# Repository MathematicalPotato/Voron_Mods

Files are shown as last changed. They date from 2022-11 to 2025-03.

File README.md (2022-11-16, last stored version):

# V0 Universal Belted Z
This is a new belted Z mod for the Voron Zero. It drops the Z drive below the bottom frame extrusion. This allows full range of motion for both stock (V0.0/V0.1/V0.2) and Kirigami setups. It has been tested with 5:1 gearing up to 300mm/s at 1000mm/s/s z accels and 200mm/s at 3000mm/s/s with an OMC-17HS08-1004S motor set to run_current: 0.5.

If you are installing fresh you will need to install the motor plate after installing the rear panel (the rest of the Z drive can be installed before).  You will also need to install the bedmount prior to mounting the back panel for the stock bed setups as they bolt from the back.  For the Kirigami the whole thing can be installed without removing the panel.

For the Z Drive itself, you will need three F695 bearings, a 200mm GT2 belt loop, and a 5mm OD by 75mm long shaft with flats for pulleys.  Longer shafts will also work (I am using a 100mm currently because I was too lazy to cut it shorted) as long as you set the end flush with the pulley in the 80 tooth, but you'll need to restrain cables to ensure they don't get near the shaft.

For the upper idler there are two models, one that can use F695 bearings and one for F623 bearings. I highly recommend using F623 bearings as the belt alignment will be a little bit better and if you're building a V0 you probably have two extras.

For bolt/nut/heatset counts they should all be in place in the CAD, each configuration has slight differences.

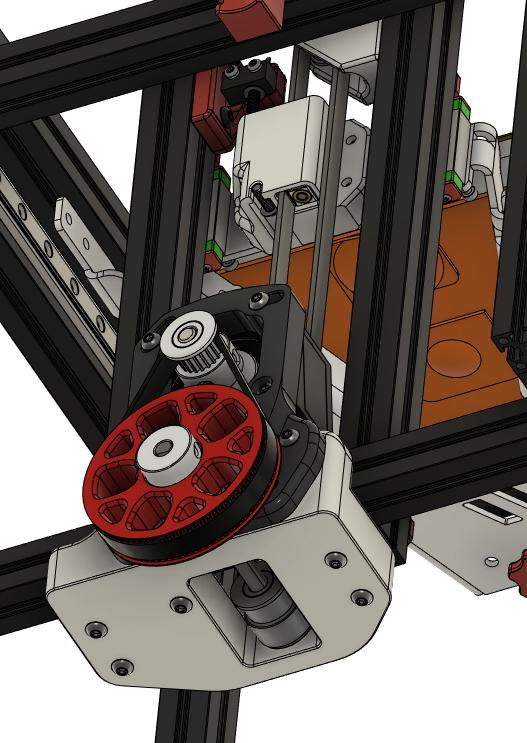
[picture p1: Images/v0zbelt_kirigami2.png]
ZBelt-Pic001

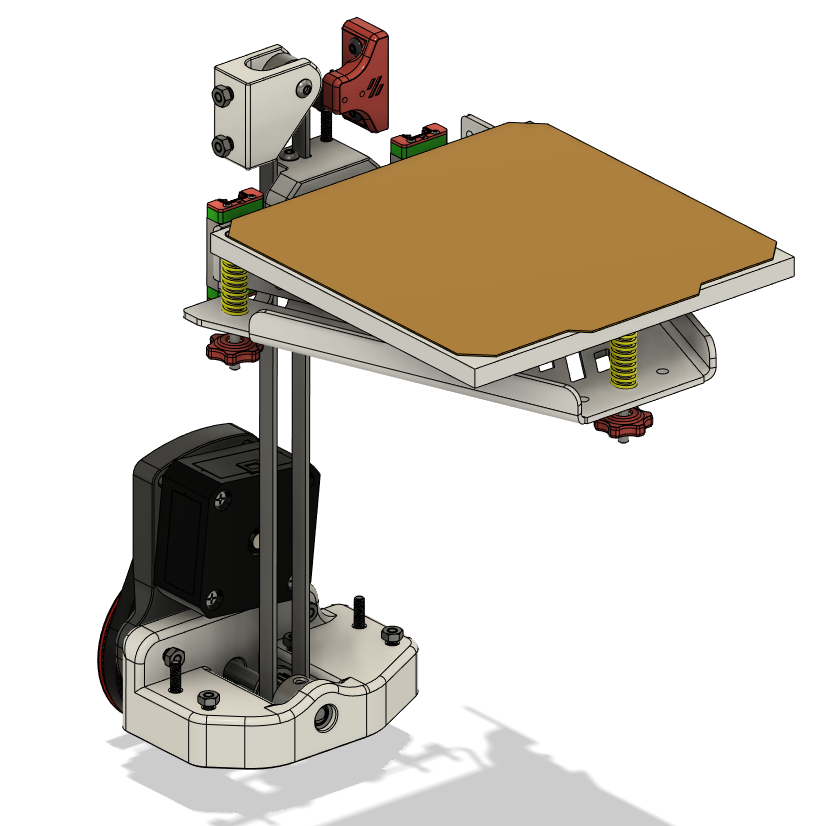
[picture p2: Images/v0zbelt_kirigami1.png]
ZBelt-Pic002

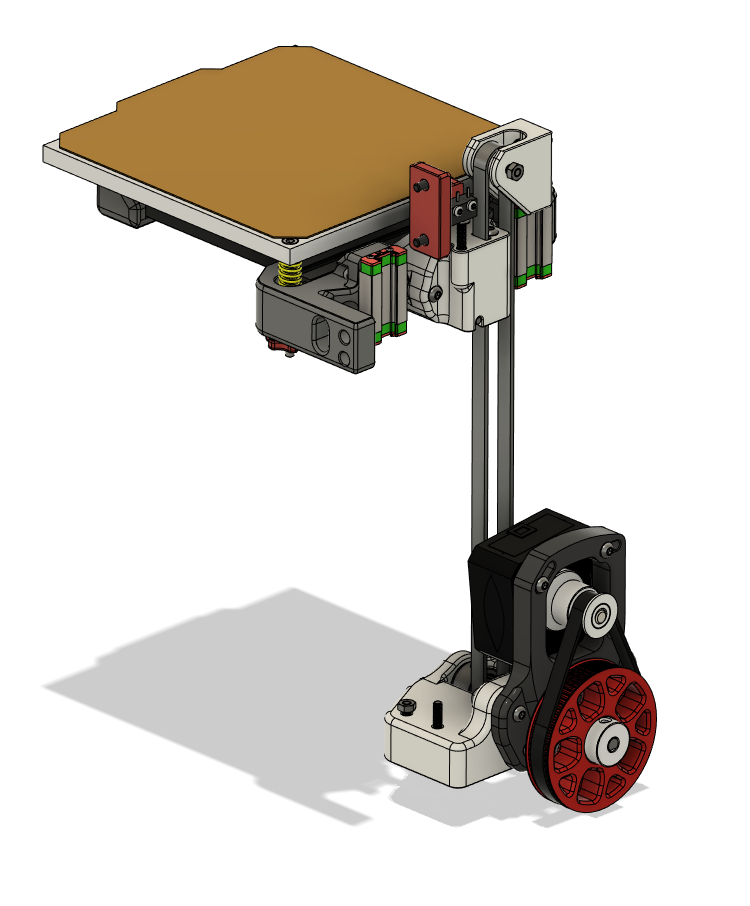
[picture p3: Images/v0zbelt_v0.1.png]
ZBelt-Pic003


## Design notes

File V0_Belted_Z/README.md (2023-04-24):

# V0 Universal Belted Z
This is a new belted Z mod for the Voron Zero. It drops the Z drive below the bottom frame extrusion. This allows full range of motion for both stock (V0.0/V0.1/V0.2) and Kirigami setups. It has been tested with 5:1 gearing up to 300mm/s at 1000mm/s/s z accels and 200mm/s at 3000mm/s/s with an OMC-17HS08-1004S motor set to run_current: 0.5.

If you are installing fresh you will need to install the motor plate after installing the rear panel (the rest of the Z drive can be installed before).  You will also need to install the bedmount prior to mounting the back panel for the stock bed setups as they bolt from the back.  For the Kirigami the whole thing can be installed without removing the panel.

For the Z Drive itself, you will need three F695 bearings, a 200mm GT2 belt loop, and a 5mm OD by 75mm long shaft with flats for pulleys.  Longer shafts will also work (I am using a 100mm currently because I was too lazy to cut it shorted) as long as you set the end flush with the pulley in the 80 tooth, but you'll need to restrain cables to ensure they don't get near the shaft.

For the upper idler there are two models, one that can use F695 bearings and one for F623 bearings. I highly recommend using F623 bearings as the belt alignment will be a little bit better and if you're building a V0 you probably have two extras.

For bolt/nut/heatset counts they should all be in place in the CAD, each configuration has slight differences.

## Updates

### 2023-04-24

It was brought to my attention by mapaba#0044 on the Discord that there were some clearance issues with the rear skirt and power inlet on the V0.2 which could be fixed by mirroring the assembly to shift the z drive further from the power inlet.  All components have been switched to a mirrored assembly for better compatibility with V0.2 parts while maintaining compatibility with the other configurations as well.  

The old parts are still fine for V0.0 or V0.1 builds, but for new build V0.2 or upgrading to V0.2 from a prior revision it is recommended to use the new mirrored assembly.  Drilling a hole in the rear panel may be required to use the mirrored z-min endstop. It is recommended to use the newer z-max endstop configuration.

This mod is compatible with V0.0, V0.1, and V0.2 in either Kirigami or Stock Bed configurations as of 2023-04-24.

## Pictures

### Kirigami Bed

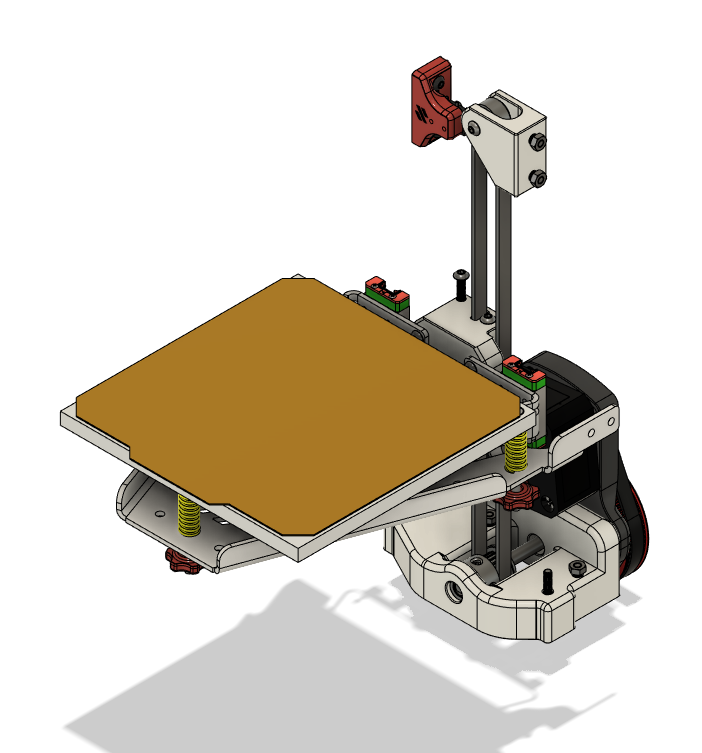
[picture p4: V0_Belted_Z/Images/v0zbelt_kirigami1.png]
ZBelt-Pic001

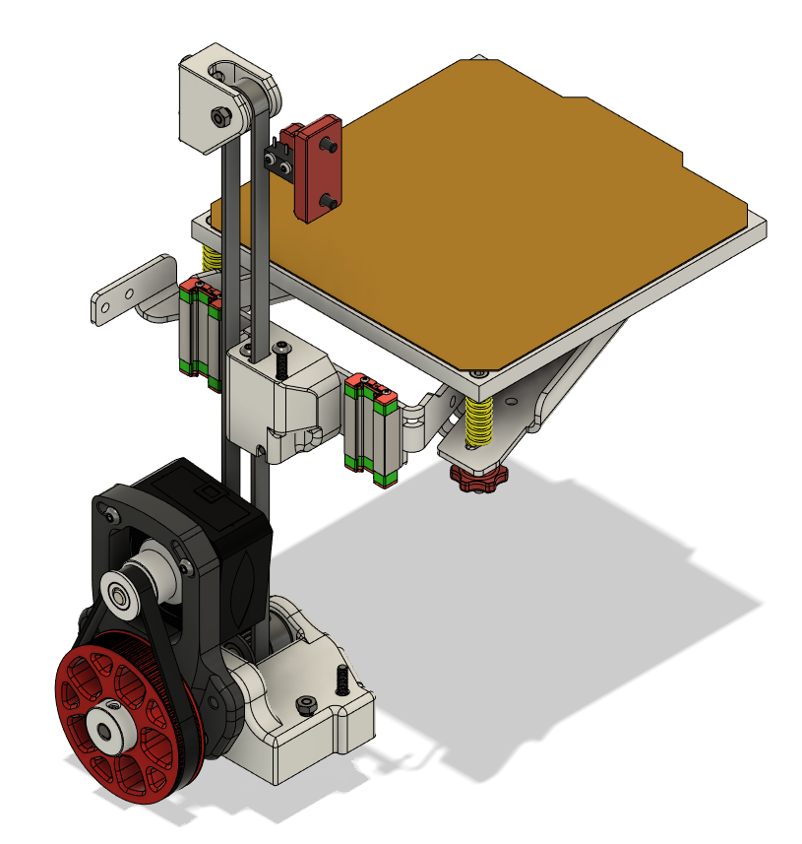
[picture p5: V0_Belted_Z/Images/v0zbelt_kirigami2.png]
ZBelt-Pic002


### Stock Bed

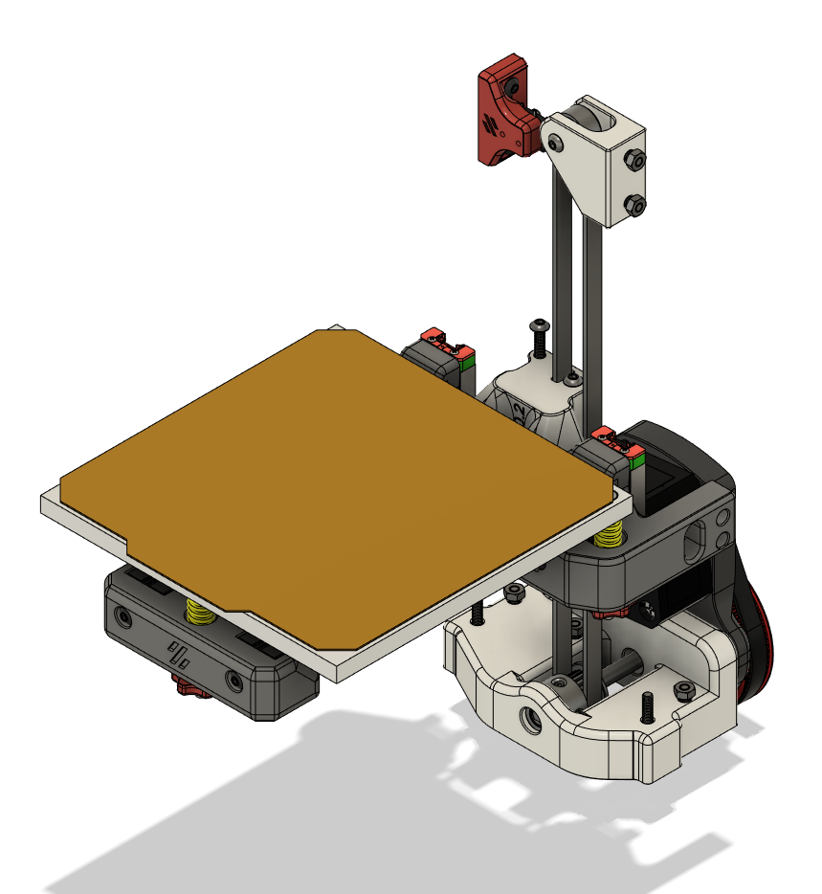
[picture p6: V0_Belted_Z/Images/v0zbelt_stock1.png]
ZBelt-Pic003


### V0.2 Compatibility

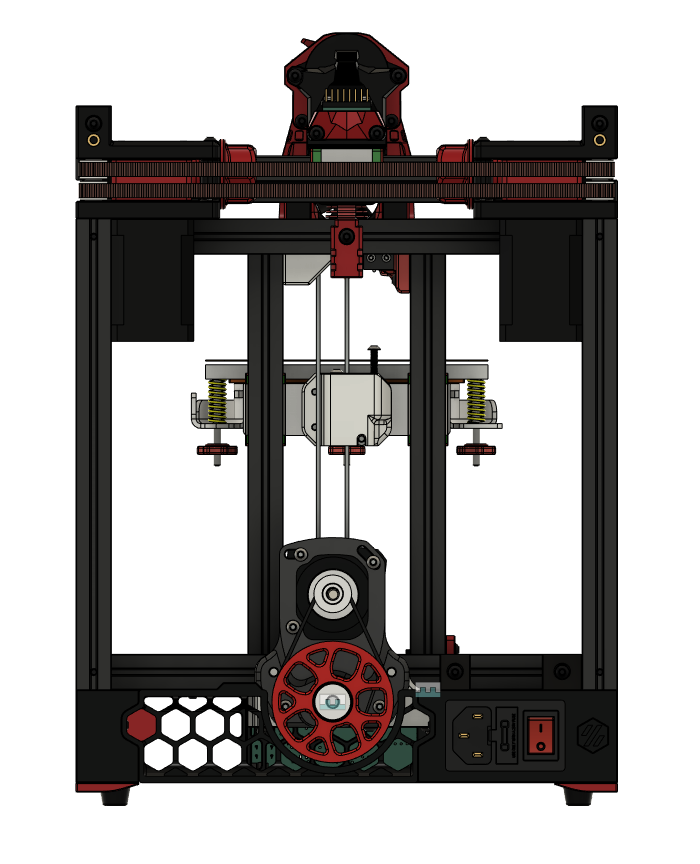
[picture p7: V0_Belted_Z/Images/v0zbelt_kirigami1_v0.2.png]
ZBelt-Pic004

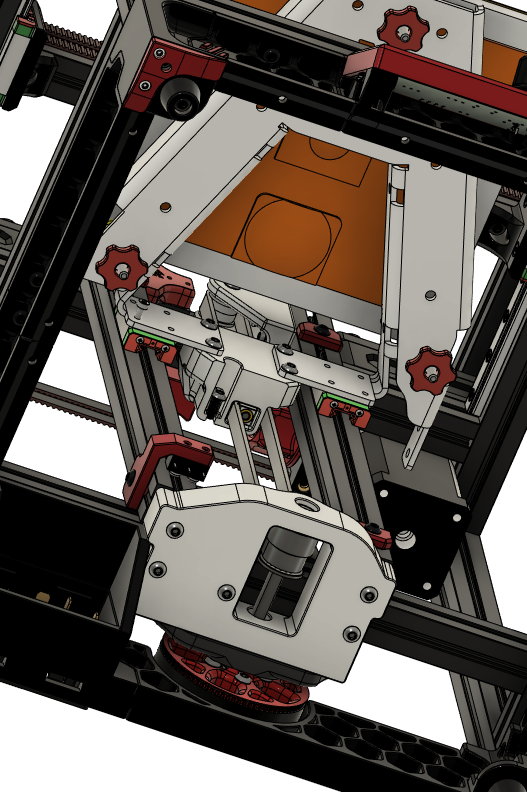
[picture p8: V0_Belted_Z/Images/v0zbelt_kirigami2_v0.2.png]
ZBelt-Pic005


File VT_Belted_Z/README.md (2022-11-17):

# VT Belted Z
This is a belted Z mod candidate for the Voron Trident.  It use three modified V2.4 Z drives in place of the integrated leadscrew steppers for Z motion.  

Parts are currently designed for 9mm belts, but 6mm belts could be used by swapping to a 6mm pulley and adding extra spacers around the idler bearings.

Check motor datasheets and try to get Z motors that have at least 0.2 mNm of detent torque, most stepper motors that are at least 48mm long will have enough.  250mm builds with beds over 8mm thick, 300mm builds with beds over 6mm thick, and all 350mm builds are not recommended as the Z motors will likely not have a high enough detent torque to hold the bed on power off.  This can cause the bed to drop which can have the same effect as spinning steppers by hand, a charge will be sent back to stepper drivers and controller board which can fry components.

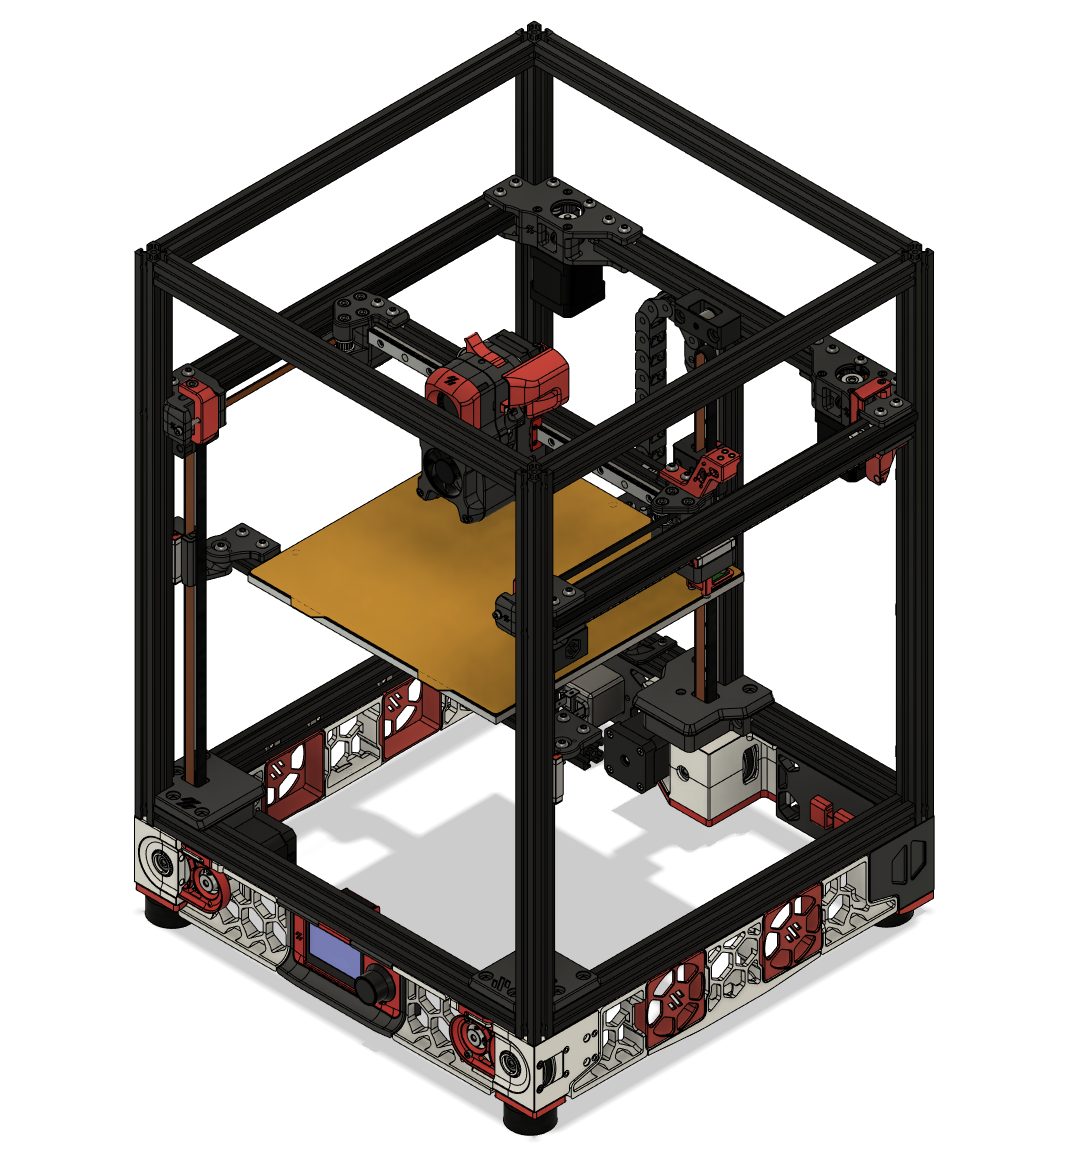
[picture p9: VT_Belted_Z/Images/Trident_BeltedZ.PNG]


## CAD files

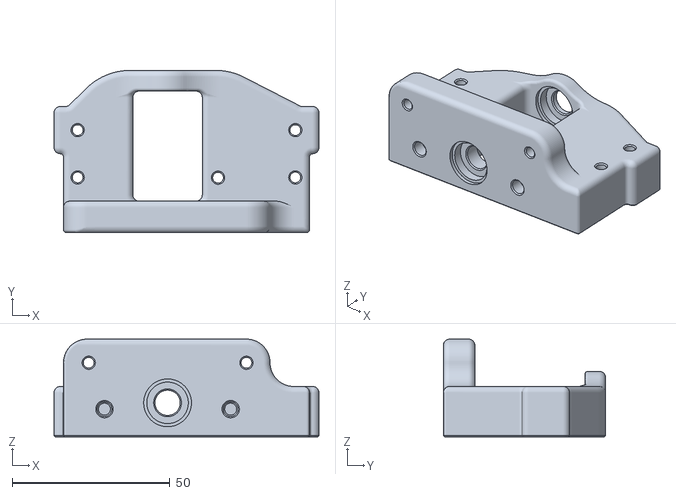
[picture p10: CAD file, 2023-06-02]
V0_Belted_Z/STLs/Mirrored Configuration - V0.2, V0.1, V0.0/z_drive_bottom_idler_pulleys_x1.stl
84.0 x 51.4 x 31.0

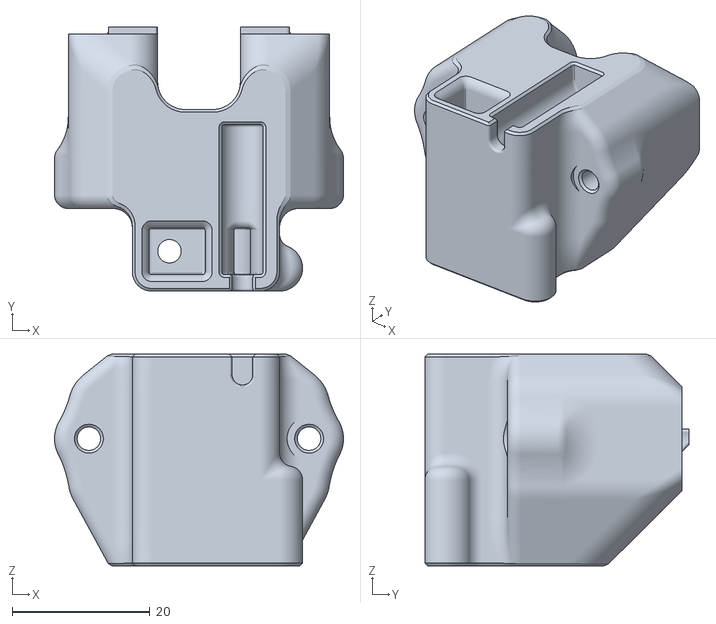
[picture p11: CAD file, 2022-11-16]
V0_Belted_Z/STLs/Original Configuration - V0.1 and V0.0/Bed_Mount_Extrusions_V0.1.stl
42.0 x 38.4 x 30.8

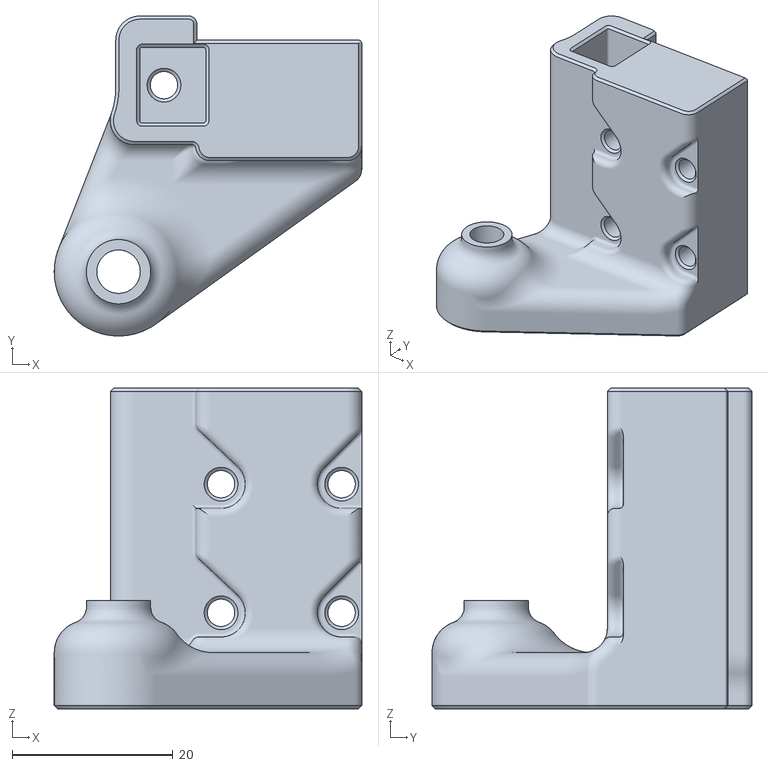
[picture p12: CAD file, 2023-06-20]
VT_Belted_Z/STLs/Trident_BeltedZ_Drives/front_left_drive/left_carriage_mount.stl
38.2 x 39.8 x 39.9

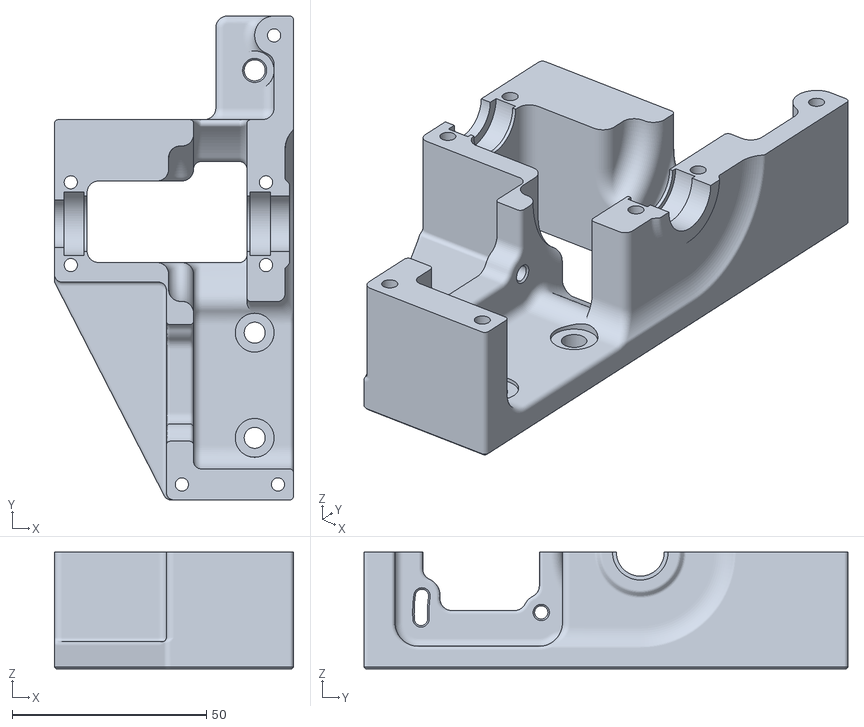
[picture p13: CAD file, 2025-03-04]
VT_Belted_Z/STLs/Trident_BeltedZ_Drives/rear_drive/rear_z_top.stl
61.5 x 124.6 x 30.0

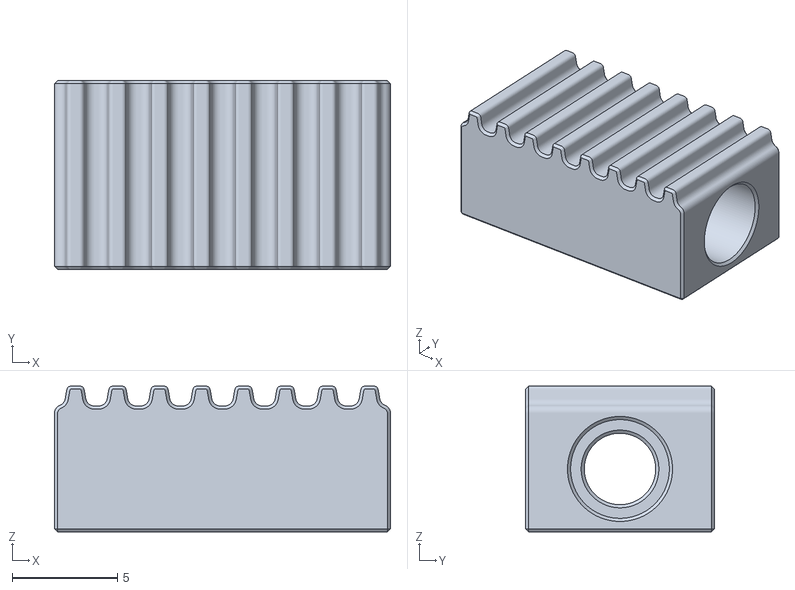
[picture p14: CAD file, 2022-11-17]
VT_Belted_Z/STLs/Trident_BeltedZ_Drives/tensioner_slider_x3.stl
16.0 x 9.00 x 6.95

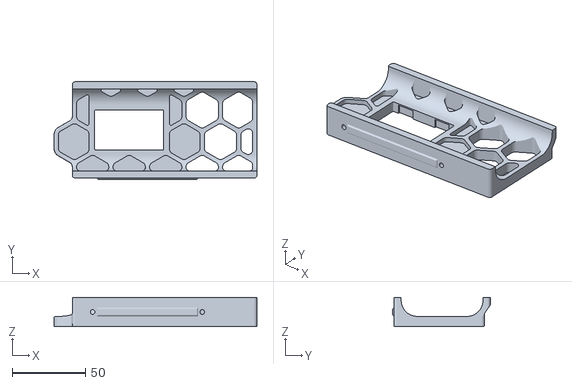
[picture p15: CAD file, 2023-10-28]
VT_Belted_Z/STLs/Trident_BeltedZ_Skirts/power_inlet_adamstech_300.stl
139.0 x 66.8 x 20.0

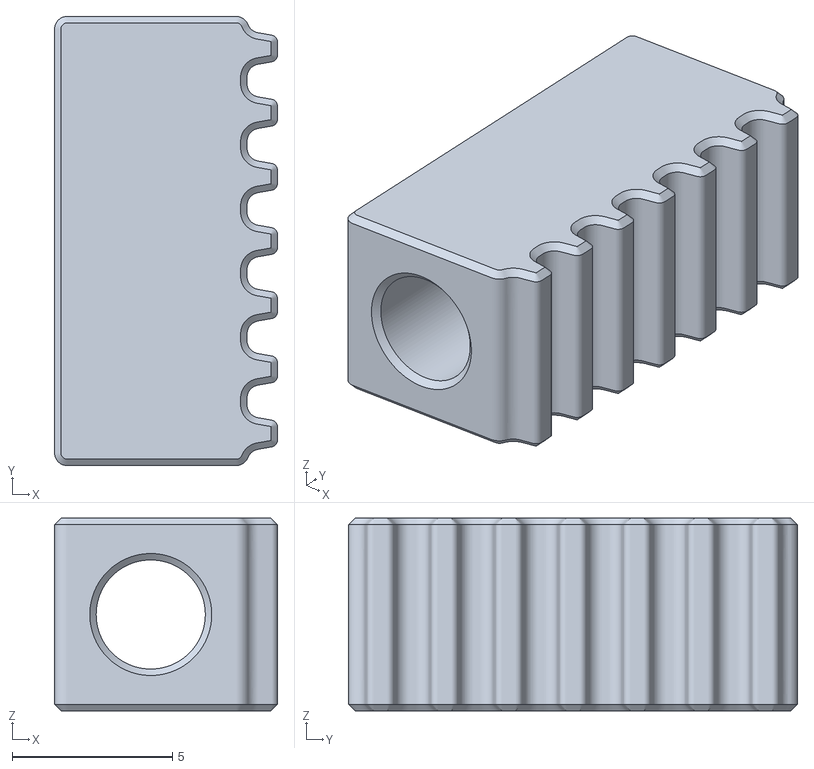
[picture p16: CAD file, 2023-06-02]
V0_Belted_Z/STLs/Mirrored Configuration - V0.2, V0.1, V0.0/Bed_Mount_Tensioning_Block.stl
6.95 x 14.0 x 6.00

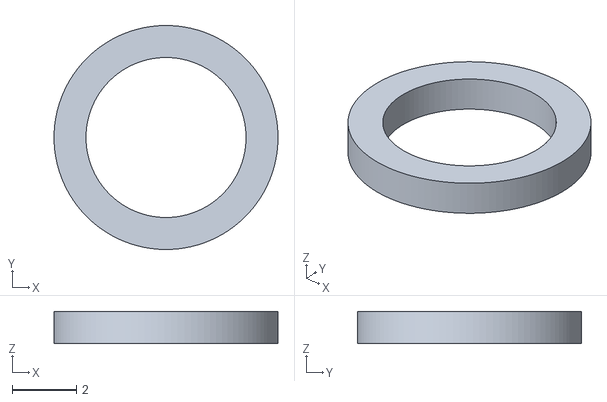
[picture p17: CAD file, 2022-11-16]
V0_Belted_Z/STLs/Original Configuration - V0.1 and V0.0/Printed-PulleySpacer-OPTIONAL.stl
7.00 x 7.00 x 1.00

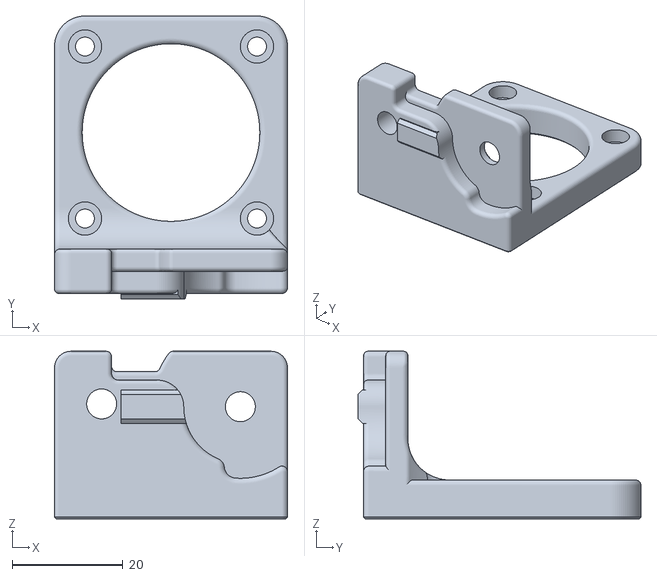
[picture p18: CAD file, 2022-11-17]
VT_Belted_Z/STLs/Trident_BeltedZ_Drives/front_left_drive/left_z_drive_motor_mount.stl
42.0 x 51.0 x 30.2

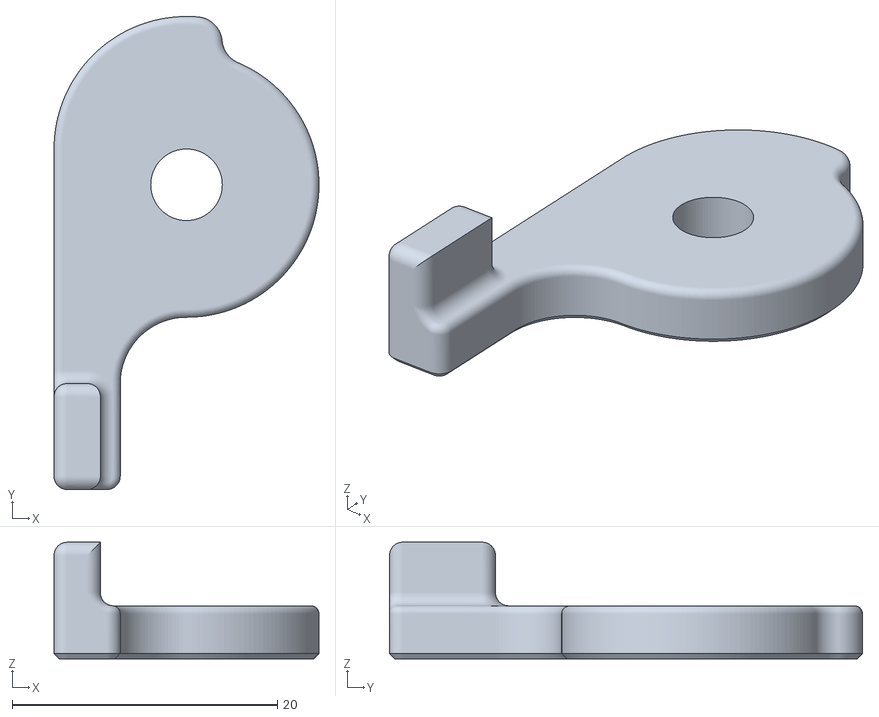
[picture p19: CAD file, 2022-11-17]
VT_Belted_Z/STLs/Trident_BeltedZ_Drives/front_right_drive/[a]_right_z_drive_tensioner.stl
20.0 x 35.7 x 8.80

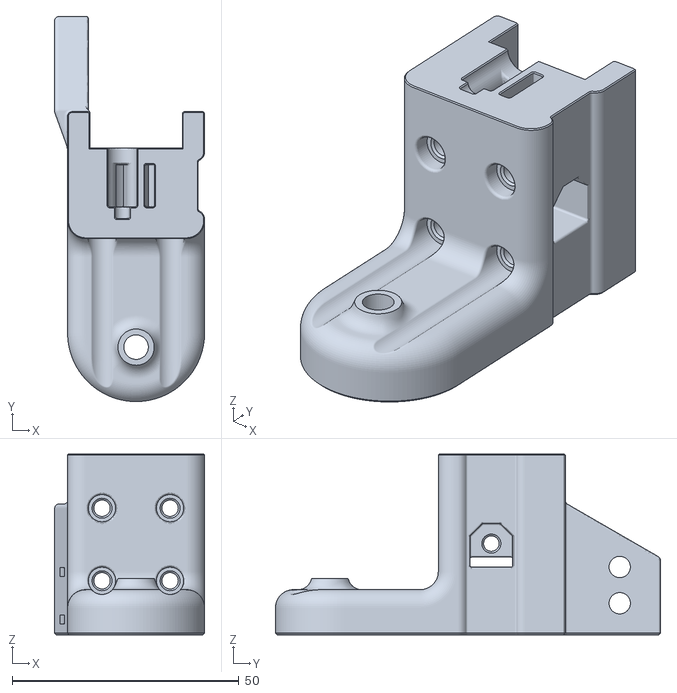
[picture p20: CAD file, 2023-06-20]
VT_Belted_Z/STLs/Trident_BeltedZ_Drives/rear_drive/rear_z_carriage_2hole.stl
33.1 x 84.9 x 39.9

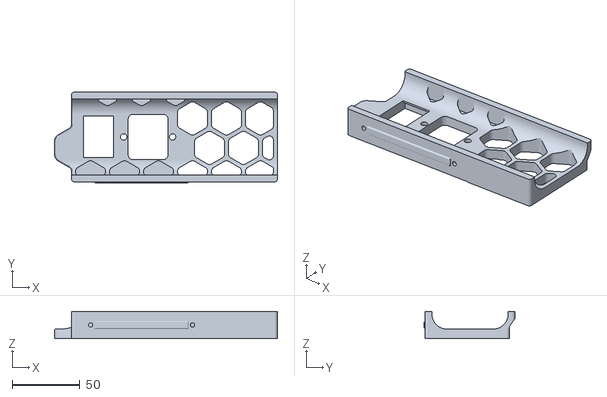
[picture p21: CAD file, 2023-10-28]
VT_Belted_Z/STLs/Trident_BeltedZ_Skirts/power_inlet_filtered_350.stl
164.0 x 66.8 x 20.0

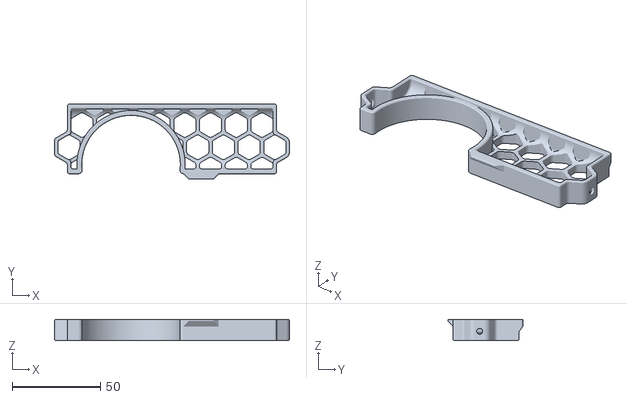
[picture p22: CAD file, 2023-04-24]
V0_Belted_Z/STLs/Mirrored Configuration - V0.2, V0.1, V0.0/z_rear_skirt_belted_z.stl
132.8 x 42.5 x 12.0

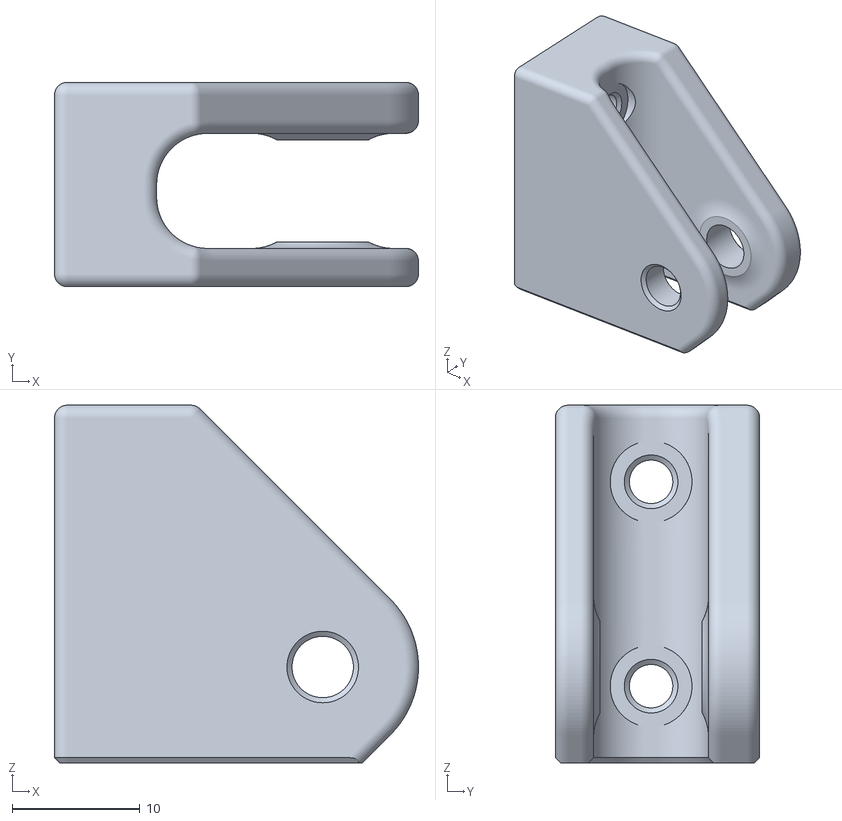
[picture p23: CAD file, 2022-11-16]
V0_Belted_Z/STLs/Original Configuration - V0.1 and V0.0/z_top_idler_F695.stl
28.5 x 16.0 x 28.0

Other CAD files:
VT_Belted_Z/STLs/Trident_BeltedZ_Drives/front_right_drive/right_carriage_mount.stl
VT_Belted_Z/STLs/Trident_BeltedZ_Drives/front_left_drive/[a]_left_z_drive_base_plate.stl
VT_Belted_Z/STLs/Trident_BeltedZ_Drives/front_right_drive/right_z_drive_body_outer.stl
VT_Belted_Z/STLs/Trident_BeltedZ_Drives/rear_drive/rear_z_bottom.stl
V0_Belted_Z/STLs/Mirrored Configuration - V0.2, V0.1, V0.0/Bed_Mount_Extrusions_V0.0+0.2.stl
V0_Belted_Z/STLs/Mirrored Configuration - V0.2, V0.1, V0.0/Bed_Mount_Extrusions_V0.1.stl
V0_Belted_Z/STLs/Mirrored Configuration - V0.2, V0.1, V0.0/Bed_Mount_Kirigami.stl
V0_Belted_Z/STLs/Mirrored Configuration - V0.2, V0.1, V0.0/M4-80T-Gear.stl
V0_Belted_Z/STLs/Mirrored Configuration - V0.2, V0.1, V0.0/z_drive_motor_mount_pulleys_x1.stl
V0_Belted_Z/STLs/Mirrored Configuration - V0.2, V0.1, V0.0/z_endstop_mirror.stl
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

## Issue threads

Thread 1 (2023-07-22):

How many N.m do we need for 350mm?

pasha4ur, 2023-07-22:
Hello

Thank you for this mod.

How many N.m do we need for 350 mm with standard thickness?

You wrote:
> try to get Z motors that have at least 0.2 mNm of detent torque

For example 40 mm motor (I have this):

Cloudray Nema 17 Stepper Motor  40mm 0.42 N.m 1.7A 2 Phase
https://ae01.alicdn.com/kf/Heec5ff7f53b0446ba1fe4dcbd27f9fbbB.jpg
https://www.aliexpress.com/item/1005001303445983.html

or 60 mm:

Nema17 Stepper Motor 60mm 2 Phase 71 N.m 1.8A Stepper Motor
https://www.aliexpress.com/item/4000934544704.html

I'm building Trident with build volume 450 mm. But for this moment I have standard 350 mm build plate.

MathematicalPotato, 2023-09-14:
You're looking for the detent torque rating of the steppers not the holding torque.  Holding torque is how much torque it takes to turn the motor shaft when powered on and running at the rated current.  Detent torque is the amount of torque it takes to turn the shaft when no power is applied.  For beds, we are more interested in the detent torque rating as if this value is not spec'd high enough compared to the Z axis moving mass, the bed will drop on power off.  This can break components depending on the weight of the bed or fry electronics if the steppers back feed into the controller board.

For reference, a torque rating of 1Nm with a 16T/20T pulley on the motor shaft and 1:1 gearing should hold about 40lbs per motor.  This reference value is higher than the powered (holding) torque rating of pretty much every NEMA17 stepper targeted at 3DP.  For steppers that do not have data sheets or that do not have detent torque listed on the data sheets I would either compare to a comparable LDO model or assume detent torque is somewhere around 2-4% of the holding torque.  It can also be measured using an arm of a known length bolted to the motor and pushing that shaft against a kitchen scale and recording the maximum mass.  It takes some math to get back to detent torque, but it's a good method if there isn't any other data.

The 60mm long NEMA17s seem to have the highest detent torque available, but they still top out around 0.030Nm of detent torque.  This value should be able to hold about 3.7lbs per motor without power on 5:1 gearing.  My belted Z design uses 3 drives which would only be able to hold an absolute maximum of ~11.1lbs with these motors.  Based on some quick math, I estimate a 9mm thick 350mm bed assembly (with bed mounts, extrusions, etc) for a Trident would weight approximately 13lbs.  This also doesn't account for print mass.  With these values, I would not recommend running 5:1 belted Z for machines larger than 300mm.

I would recommend looking into worm gear Z drives similar to the style used on the Z axis of the Annex Engineering K1/K2 and Redoubt as they can provide significantly higher gear reductions.  A minimum of 10:1 gearing would be ideal for your machine size.

Closed 2023-09-14.

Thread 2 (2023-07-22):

Can you make it compatible with Idex's idlers?

pasha4ur, 2023-07-22:
Hello.

With belted Z and Idex trident can shine with more power. )

https://github.com/FrankenVoron/Tridex/blob/main/Documentation/Assembly_Manual_Tridex_Front_Idler.pdf

MathematicalPotato, 2023-09-14:
This should be possible with the existing parts, but would likely require shorter Z rails, taller bed standoffs, and a reduced Z travel compared to a stock machine in the same frame size.  It is outside the scope of this mod, but a lot of the design elements could be reused.

Closed 2023-09-14.

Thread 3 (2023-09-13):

SolidWorks Corporation - STEP Processor Error Log

pasha4ur, 2023-09-13:
Hello

I know that you don't care about users and don't answer but your new step file has problems:

SolidWorks Corporation - STEP Processor Error Log
STEP Post Processor

Error: Encountered invalid record index.
STEP-in did not complete successfully.

MathematicalPotato, 2023-09-14:
I rarely check Github as don't make regular updates to these mods and I typically get <5 requests per year for updates.  Previously they also all have been though Discord, either in DMs or on the Voron server.  I am far more responsive on Discord (mathematicalpotato) if you need more immediate assistance with an issue or have a quick question.

I am unsure which STEP file you are referring to, but I just downloaded both the V0 and VT Belted Z CAD files and both open without issues for me in Fusion360.  This is likely an issue with the way SolidWorks handles STEP files and unfortunately I cannot replicate it.  I have attached a double zipped IGES file which may work better for you:

[Voron_Trident_BeltedZ_IGES_2.zip](https://github.com/MathematicalPotato/Voron_Mods/files/12602782/Voron_Trident_BeltedZ_IGES_2.zip)

Closed 2025-03-04.

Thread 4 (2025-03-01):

Rear z motor top stl is incorrect file

axg20202, 2025-03-01:
The STL for this part has the single heat insert in the wrong place for the motor cover. The part in the CAD is correct.

MathematicalPotato, 2025-03-04:
Thank you for letting me know.  Not at all sure how this happened, but I just swapped it out for the correct file.

https://github.com/MathematicalPotato/Voron_Mods/blob/main/VT_Belted_Z/STLs/Trident_BeltedZ_Drives/rear_drive/rear_z_top.stl

Closed 2025-03-04.

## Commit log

2022-11-16 Create folder for CAD assembly
2023-04-24 Create CAD
2023-04-24 Updated CAD
    Updated CAD with mirrored parts for better V0.2 compatibility.
2023-04-24 Updated STLs for better V0.2 compatibility
    Updated assembly to be mirrored for better V0.2 compatibility
    [Bed_Mount_Extrusions_V0.0+0.2.stl, Bed_Mount_Extrusions_V0.1.stl, Bed_Mount_Kirigami.stl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]
2023-06-02 Updated STLs
    z_drive_bottom_idler_pulley_x1.stl - add missing mount holes
    Bed_Mount_Tensioning_Block.stl - increase length to grab a few extra belt teeth for better grip
    [Bed_Mount_Tensioning_Block.stl, z_drive_bottom_idler_pulleys_x1.stl]
2023-06-02 Create CAD folder
2023-06-20 Add files via upload
    Fixed hole spacing
    [right_carriage_mount.stl]
2023-06-20 Add files via upload
    Fixed hole spacing and removed outdated versions
    [rear_z_carriage_2hole.stl, rear_z_carriage_3hole.stl, rear_z_tensioning_slider.stl]
2023-06-20 Add files via upload
    Updated carriage mount hole spacing
2023-10-28 Delete VT_Belted_Z/STLs/Trident_BeltedZ_Skirts/power_inlet_adamstech.stl
    Removed to replace with 250, 300, and 350 versions
    [power_inlet_adamstech.stl]
2023-10-28 Delete VT_Belted_Z/STLs/Trident_BeltedZ_Skirts/power_inlet_filtered.stl
    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
    [power_inlet_filtered.stl]
2023-10-28 Delete VT_Belted_Z/STLs/Trident_BeltedZ_Skirts/keystone_panel.stl
    Removed to replace with 250, 300, and 350 versions.
    [keystone_panel.stl]
2023-10-28 Replaced rear power inlet and keystone skirts
    Added 250, 300, and 350 sized versions of the rear power inlet and keystone skirts to better fit the rear Z drive.
    [keystone_panel_250.stl, keystone_panel_300.stl, keystone_panel_350.stl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]
2023-10-28 Delete VT_Belted_Z/STLs/Trident_BeltedZ_Skirts/keystone_panel_250.stl
    Replaced with properly oriented file
    [keystone_panel_250.stl]
2023-10-28 Delete VT_Belted_Z/STLs/Trident_BeltedZ_Skirts/keystone_panel_300.stl
    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
    [keystone_panel_300.stl]
2023-10-28 Delete VT_Belted_Z/STLs/Trident_BeltedZ_Skirts/keystone_panel_350.stl
    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
    [keystone_panel_350.stl]
2023-10-28 Delete VT_Belted_Z/STLs/Trident_BeltedZ_Skirts/power_inlet_adamstech_250.stl
    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
    [power_inlet_adamstech_250.stl]
2023-10-28 Delete VT_Belted_Z/STLs/Trident_BeltedZ_Skirts/power_inlet_adamstech_300.stl
    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
    [power_inlet_adamstech_300.stl]
2023-10-28 Delete VT_Belted_Z/STLs/Trident_BeltedZ_Skirts/power_inlet_adamstech_350.stl
    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
    [power_inlet_adamstech_350.stl]
2023-10-28 Delete VT_Belted_Z/STLs/Trident_BeltedZ_Skirts/power_inlet_filtered_250.stl
    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
    [power_inlet_filtered_250.stl]
2023-10-28 Delete VT_Belted_Z/STLs/Trident_BeltedZ_Skirts/power_inlet_filtered_300.stl
    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
    [power_inlet_filtered_300.stl]
2023-10-28 Delete VT_Belted_Z/STLs/Trident_BeltedZ_Skirts/power_inlet_filtered_350.stl
    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
    [power_inlet_filtered_350.stl]
2023-10-28 Fixed STL orientation for printing.
    Replaced STLs for power inlet and keystone skirts with files that are properly oriented for printing.
    [keystone_panel_250.stl, keystone_panel_300.stl, keystone_panel_350.stl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]
